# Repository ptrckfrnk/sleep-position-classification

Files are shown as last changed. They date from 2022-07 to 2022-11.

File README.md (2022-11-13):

# Electronic Technologies and Biosensors Laboratory

## Academic Year 2021/2022 - II Semester

## Final Project - Project 5 - Sleep position classifier
## Objective


The aim of this project was to develop a system able to correctly classify and forecast **12 specific sleep positions** (visible in the image above), using the data from **two accelerometers LIS3DH** placed one on the chest and one on the right ankle. 
The finished project includes: 
- development of the wearable device
- data acquisition
- data processing
- GUI for data sampling and visualization
- machine learning architecture able to perform sleep position classification

The PSoC communicates with the LIS3DH sensors using **I2C communication**, and the accelerometers have a sampling frequency set at 10Hz. 
The communication between the PSoC device and the pc was created using a **HC05 Bluetooth module** to make the device wearable.
Also, for wearability, the device is powered with a **9V battery** and a subsequent **9 to 5 voltage transformer**.
### Hardware
- 2 LIS3DH accelerometers
- 1 HC05 Bluetooth module
- 1 9V battery
- 1 9to5 voltage transformer
- 1 PSoC CY8CKIT-059 
- 1 breadboard
- 2 3D printed casings were used to encapsulate the accelerometers and place them on the body
- 10 2m long cables to connect the accelerometers to the PSoC
- 2 modular velcro bands to fix the accelerometers in place 

The links between the PSoC and the different components can be found in the dedicated folder in the form of the **hardware** **setup** documentation and the eagle schematic and board files.
The casing's 3D model can also be found in the dedicated folder.

### PSoC code
This section of code is responsible for I2C communication between the PSoC and the 2 accelerometers, which are sampling data with an ODR of 10Hz and are set on **FIFO mode**. The following code averages the 32 samples of the FIFO buffer from both accelerometers, each time they are simultaneously full.
Finally, the 6 averaged acceleration values (x, y and z from the chest and the ankle) are combined in a unique string and managed by the **UART** of the bluetooth module, having a baudrate of 9600 bps.

All code files of this section have been individually commented on for clarity.

### GUI code

This section of code deals with establishing a connection between pc and bluetooth module, visualizing the data sampled in real-time, and producing csv files following a specific sampling protocol, which are further used to train the machine learning module. 
It follows a description of the most important subsections of code, but the code has been commented throughout for clarity.
#### $Serial$ $interface$
This subsection is devoted to scanning all serial ports and creating a list used in the dropdown menu.
#### $Serial$ $Worker$
The **SerialWorker** class handles the connection with the bluetooth module by establishing a connection with the desired serial port (selectable in a drop down menu), reading data from this port from start (S) to end (E) tokens as soon as the Start button is pressed, **storing iteratively** the read lines in the data object and saving them at the end of the protocol in a single csv file.  
It's also responsible for sending char data on the serial port and closing the serial port before closing the app.
#### $Graphic$ $interface$ 
This sub-section of code deals with creating the **window** used by all the plot widgets and the various **buttons**. 
It's worth noting that the 6 data charts are plotted on the same window by first removing the oldest point, then adding the new one, and finally updating the data.
#### $Main$
The main is responsible for setting the **window size**, creating the **thread handler** and **initializing** all the **functions** previously mentioned.

### Machine Learning
#### $Install$

The Machine Learning portion of this project was created using a Jupyter Notebook.
The library used are available in the *requirements.txt* file inside the *machine learning folder* and any function needed is clearly listed and commented troughout the code.

#### $Data$
In order to run the code, it's necessary to upload the csv files produced by us during the sampling. All the paths are stored in a distinct variable.

The data consists in 11 csv files sampled from 11 different people, it's worth nothing that the file 'fabio_20220601_193018.csv' was discarted 
due to errors during the sampling procedure, thus we ended up with 10 different people, a sample size big enough to guarantee inter-subject variabilty.

The data available was studied in three different ways, in order to see if the accuracy of the model could be improved:
- **Raw** sampled data
- **Average** of data for each sensor
- **Average** of data for each sensor + **minimun and maximum** values for each sensor

#### $Data Preprocessing$
It's important to note that the **first 20 samples of each position recording were removed**, due to the patient still not being completely settled down and ready for the sampling. 
The data was also **normalized** as good practice dictates.

#### $Data Visualization$
The data was visualized multiple times, this allowed us to purge it from artifacts and anomalies and improve the learning algorithm, such as the *transient
data* between two positions mentioned in the previous paragraph.

#### $Features$
The data was gathered from 2 accelerometers, one on the chest and one on the right ankle. Therefore we have 6 inputs + 1 input for the subject's sex.
- x_chest
- y_chest
- z_chest
- x_ankle
- y_ankle
- z_ankle
- sex

#### $Target Variable$
The variable that we need to predict is the sleeping position. It can be one of twelve positions.

##### $Run$
To run the code, simply run sequentially every data cell. 
The code was tested on all three datasets, and the best performing one turned out to be the **Random Forest Classifier** learned using the **average+min_max** dataset, which reached **50% of accuracy** on the test set.

#### $Master Position$
In order to better assess the performance of the classifier we also tested it only on the four "master" positions: by grouping by three the positions (and therefore eliminating the small variations between each of the main positions) we obtained the **main positions**: supine, prone, left-sided and right-sided. 
When we tested our algorithm only with these targets, we easily obtained **100% accuracy**.

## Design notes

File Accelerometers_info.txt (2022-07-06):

Accelerometer 01 - Address 0x18 - Chest
Accelerometer 02 - Address 0x19 - Ankle

Ankle accelerometer has a black scotch mark, SD0 pin needs to be connected to Vin
Chest accelerometer SD0 pin needs to be connected to Gnd

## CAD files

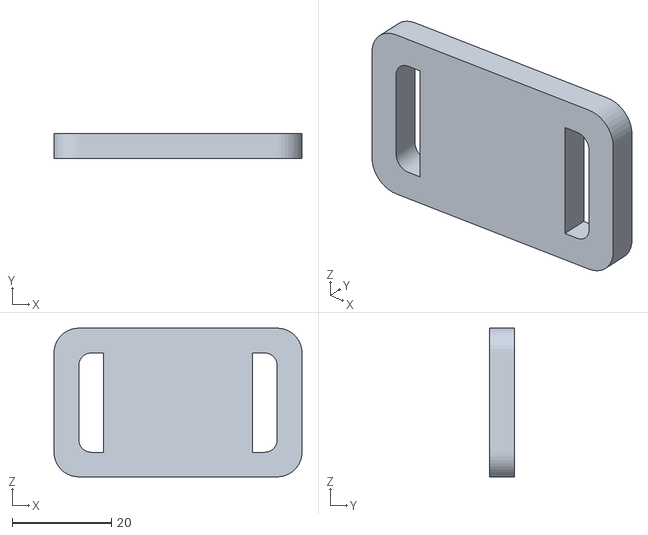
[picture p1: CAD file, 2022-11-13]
3D_Printing/Accelerometer_casing.STL
50.0 x 5.00 x 30.0

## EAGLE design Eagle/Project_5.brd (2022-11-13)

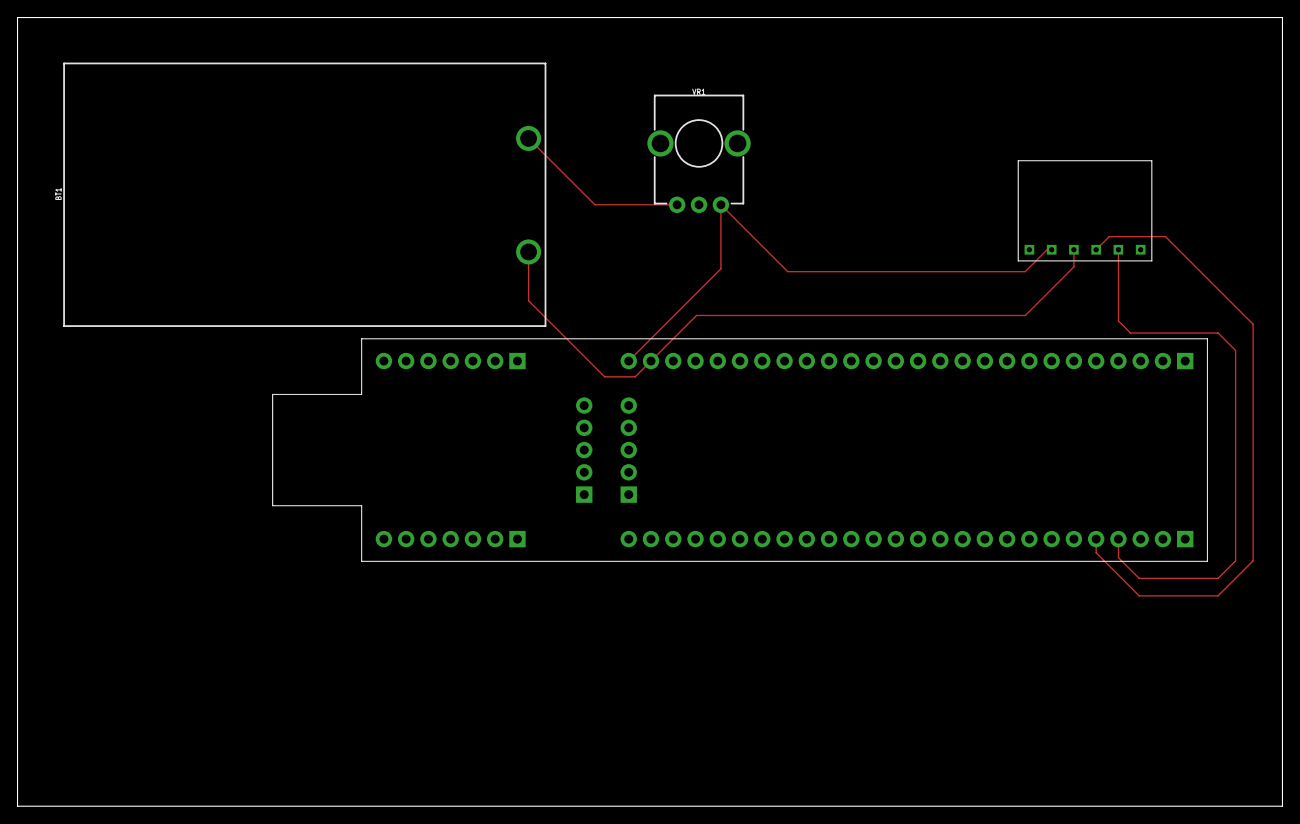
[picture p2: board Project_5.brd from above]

Board: 2 copper layers, 144.3 x 90.0 mm, 4 parts (0 on the bottom side), 5 nets.

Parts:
BT1: BATTCON_9V
U$1: CY8CKIT-059
U$2: HC; HC-05
VR1: 10k; POT-PTH-ALPS-KIT

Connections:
unnamed: BT1.-, U$1.25, U$2.P$4
unnamed: U$1.30, U$2.P$2
unnamed: U$1.31, U$2.P$3
unnamed: U$1.26, U$2.P$5, VR1.P$3
unnamed: BT1.+, VR1.P$1

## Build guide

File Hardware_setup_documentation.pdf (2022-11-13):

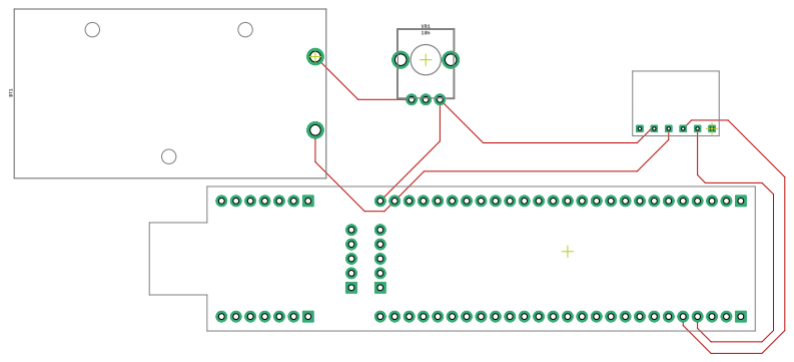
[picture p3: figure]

This board (on the right) is included in the documentation only for detailing purposes, since we did not produce a pcb (as it would have been superfluous). If one wanted to do it, only the components shown here (psoc, voltage transformer, bluetooth module and battery) would be needed, while the accelerometers would still need to be linked using external cables.

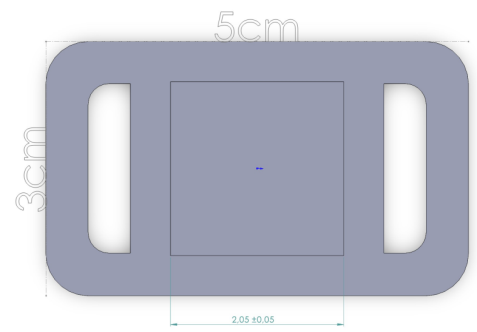
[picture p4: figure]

The casing model were created using solidworks and were then printed using the automaker software.

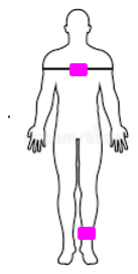
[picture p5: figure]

### Sleep Position Sensor

The hardware setup relies upon the links between the accelerometers and the bluetootooh module and the PSoC. We will describe the main connections (also visible on the pcb schematic on the left) for clarity.
Bluetooth
Rxd is linked to Port 0.7
Txd is linked to Port 0.6
Accelerometers
Scl are linked to port 12.0
Sda are linked to port 12.1
Notably, since both accelerometers are linked to same ports, in order to distinguish them we linked the Sdo of one accelerometer to the Power line, and the other one to the Ground line.

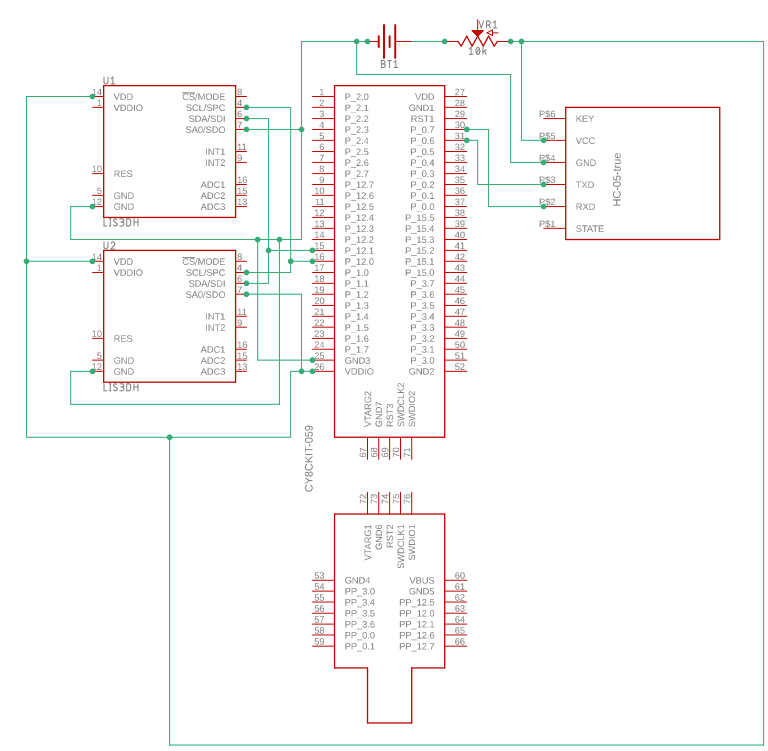
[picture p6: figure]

### Accelerometers casings

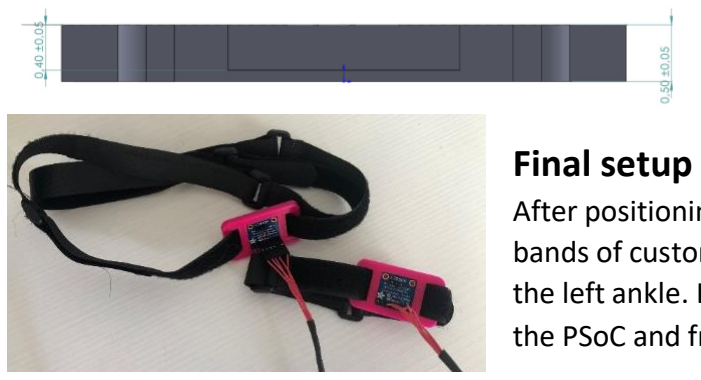
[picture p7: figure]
Final setup

After positioning the sensors inside the casings, we used velcro bands of customizable length to place them around the chest and the left ankle. Long cables (2m) were used to bring the signals to the PSoC and from there the bluetooth module sent them to the pc.

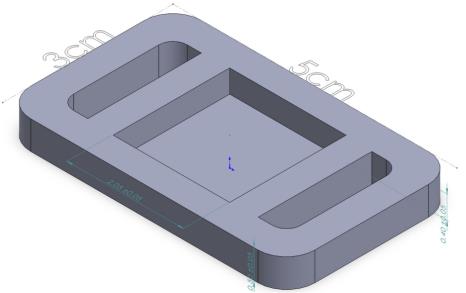
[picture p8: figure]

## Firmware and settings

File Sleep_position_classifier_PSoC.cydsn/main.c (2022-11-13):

/* ===============================================
 *
 * Alfonzo Massimo, Canavate Chloé, Franke Patrick
 * Project 05 - Sleep Position Classifier
 * Electronic Technologies and Biosensor Laboratory
 * Academic year 2021 - 2022
 * main.c file
 *
 * =============================================== */


#include <stdio.h>
#include "project.h"
#include "I2C_Interface.h"
#include "LIS3DH.h"

int main(void)
{
    CyGlobalIntEnable; /* Enable global interrupts. */

    I2C_Peripheral_Start();
    UART_BT_Start();

    CyDelay(5); // The boot procedure is complete about 5 ms after device power-up.

    // Bluetooth communication check
    UART_BT_PutString("UART BT: Communication started.\r\n");

    
    // CyDelay(100);
    
    // String to print out messages on the UART_BT
    char message[50] = {'\0'};
    
    // Read and write all the registers 
        // CTRL REG 1   (0x20)
    uint8_t ctrl_reg_1_acc_1;
    uint8_t ctrl_reg_1_acc_2;
    
    ErrorCode error_acc1 = I2C_Peripheral_ReadRegister(LIS3DH_1_DEVICE_ADDRESS, 
                                                    LIS3DH_CTRL_REG1,
                                                    &ctrl_reg_1_acc_1);
    ErrorCode error_acc2 = I2C_Peripheral_ReadRegister(LIS3DH_2_DEVICE_ADDRESS, 
                                                    LIS3DH_CTRL_REG1,
                                                    &ctrl_reg_1_acc_2);
        
            // Acc 1 reading
    if (error_acc1 == NO_ERROR) 
    {
        sprintf(message, "CTRL REG 1 value - Accelerometer 1: 0x%02X\r\n", ctrl_reg_1_acc_1);
        UART_BT_PutString(message);
    }
    else
    {
        UART_BT_PutString("I2C error while reading CTRL REG 1 - Accelerometer 1\r\n");
    }
            // Acc 2 reading
    if (error_acc2 == NO_ERROR) 
    {
        sprintf(message, "CTRL REG 1 value - Accelerometer 2: 0x%02X\r\n", ctrl_reg_1_acc_2);
        UART_BT_PutString(message);
    }
    else
    {
        UART_BT_PutString("I2C error while reading CTRL REG 1 - Accelerometer 2\r\n");
    }
    
            // Acc 1 writing if necessary
    if (ctrl_reg_1_acc_1 != LIS3DH_NORMAL_MODE_CTRL_REG1)
    {
        ctrl_reg_1_acc_1 = LIS3DH_NORMAL_MODE_CTRL_REG1;
        
        error_acc1 = I2C_Peripheral_WriteRegister(LIS3DH_1_DEVICE_ADDRESS,
                                                  LIS3DH_CTRL_REG1,
                                                  ctrl_reg_1_acc_1);
        
        if (error_acc1 == NO_ERROR)
        {
            sprintf(message, "\r\nCTRL REG 1 - Accelerometer 1 successfully written as: 0x%02X\r\n", ctrl_reg_1_acc_1);
            UART_BT_PutString(message);
        }
        else
        {
            UART_BT_PutString("\r\nI2C error while writing CTRL REG 1 - Accelerometer 1\r\n");
        }
    }

            // Acc 2 writing if necessary
    if (ctrl_reg_1_acc_2 != LIS3DH_NORMAL_MODE_CTRL_REG1)
    {
        ctrl_reg_1_acc_2 = LIS3DH_NORMAL_MODE_CTRL_REG1;
        
        error_acc2 = I2C_Peripheral_WriteRegister(LIS3DH_2_DEVICE_ADDRESS,
                                                  LIS3DH_CTRL_REG1,
                                                  ctrl_reg_1_acc_2);
        
        if (error_acc2 == NO_ERROR)
        {
            sprintf(message, "\r\nCTRL REG 1 - Accelerometer 2 successfully written as: 0x%02X\r\n", ctrl_reg_1_acc_2);
            UART_BT_PutString(message);
        }
        else
        {
            UART_BT_PutString("\r\nI2C error while writing CTRL REG 1 - Accelerometer 2\r\n");
        }
    }
    
        // CTRL REG 5   (0x24)
    uint8_t ctrl_reg_5_acc_1;
    uint8_t ctrl_reg_5_acc_2;
    
    error_acc1 = I2C_Peripheral_ReadRegister(LIS3DH_1_DEVICE_ADDRESS, 
                                             LIS3DH_CTRL_REG5,
                                             &ctrl_reg_5_acc_1);
    error_acc2 = I2C_Peripheral_ReadRegister(LIS3DH_2_DEVICE_ADDRESS, 
                                             LIS3DH_CTRL_REG5,
                                             &ctrl_reg_5_acc_2);
    
            // Acc 1 reading
    if (error_acc1 == NO_ERROR) 
    {
        sprintf(message, "CTRL REG 5 value - Accelerometer 1: 0x%02X\r\n", ctrl_reg_5_acc_1);
        UART_BT_PutString(message);
    }
    else
    {
        UART_BT_PutString("I2C error while reading CTRL REG 5 - Accelerometer 1\r\n");
    }
            // Acc 2 reading
    if (error_acc2 == NO_ERROR) 
    {
        sprintf(message, "CTRL REG 5 value - Accelerometer 2: 0x%02X\r\n", ctrl_reg_5_acc_2);
        UART_BT_PutString(message);
    }
    else
    {
        UART_BT_PutString("I2C error while reading CTRL REG 5 - Accelerometer 2\r\n");
    }
    
            // Acc 1 writing if necessary
    if (ctrl_reg_5_acc_1 != LIS3DH_NORMAL_MODE_CTRL_REG5)
    {
        ctrl_reg_5_acc_1 = LIS3DH_NORMAL_MODE_CTRL_REG5;
        
        error_acc1 = I2C_Peripheral_WriteRegister(LIS3DH_1_DEVICE_ADDRESS,
                                                  LIS3DH_CTRL_REG5,
                                                  ctrl_reg_5_acc_1);
        
        if (error_acc1 == NO_ERROR)
        {
            sprintf(message, "\r\nCTRL REG 5 - Accelerometer 1 successfully written as: 0x%02X\r\n", ctrl_reg_5_acc_1);
            UART_BT_PutString(message);
        }
        else
        {
            UART_BT_PutString("\r\nI2C error while writing CTRL REG 5 - Accelerometer 1\r\n");
        }
    }
            // Acc 2 writing if necessary
    if (ctrl_reg_5_acc_2 != LIS3DH_NORMAL_MODE_CTRL_REG5)
    {
        ctrl_reg_5_acc_2 = LIS3DH_NORMAL_MODE_CTRL_REG5;
        
        error_acc2 = I2C_Peripheral_WriteRegister(LIS3DH_2_DEVICE_ADDRESS,
                                                  LIS3DH_CTRL_REG5,
                                                  ctrl_reg_5_acc_2);
        
        if (error_acc2 == NO_ERROR)
        {
            sprintf(message, "\r\nCTRL REG 5 - Accelerometer 2 successfully written as: 0x%02X\r\n", ctrl_reg_5_acc_2);
            UART_BT_PutString(message);
        }
        else
        {
            UART_BT_PutString("\r\nI2C error while writing CTRL REG 5 - Accelerometer 2\r\n");
        }
    }
    
        //FIFO CTRL REG     (0x2E)
    uint8_t fifo_ctrl_reg_acc_1;
    uint8_t fifo_ctrl_reg_acc_2;
    error_acc1 = I2C_Peripheral_ReadRegister(LIS3DH_1_DEVICE_ADDRESS, 
                                             LIS3DH_FIFO_CTRL_REG,
                                             &fifo_ctrl_reg_acc_1);
    error_acc2 = I2C_Peripheral_ReadRegister(LIS3DH_2_DEVICE_ADDRESS, 
                                             LIS3DH_FIFO_CTRL_REG,
                                             &fifo_ctrl_reg_acc_2);
    
            // Acc 1 reading
    if (error_acc1 == NO_ERROR)
    {
        sprintf(message, "FIFO CTRL REG value - Accelerometer 1: 0x%02X\r\n", fifo_ctrl_reg_acc_1);
        UART_BT_PutString(message);
    }
    else
    {
        UART_BT_PutString("I2C error while reading FIFO CTRL REG - Accelerometer 1\r\n");
    }
            // Acc 2 reading
    if (error_acc2 == NO_ERROR )
    {
        sprintf(message, "FIFO CTRL REG value - Accelerometer 2: 0x%02X\r\n", fifo_ctrl_reg_acc_2);
        UART_BT_PutString(message);
    }
    else
    {
        UART_BT_PutString("I2C error while reading FIFO CTRL REG - Accelerometer 2\r\n");
    }
    
            // Acc 1 writing if necessary
    if (fifo_ctrl_reg_acc_1 != LIS3DH_BYPASS_MODE)
    {
        fifo_ctrl_reg_acc_1 = LIS3DH_BYPASS_MODE;
        
        error_acc1 = I2C_Peripheral_WriteRegister(LIS3DH_1_DEVICE_ADDRESS,
                                                  LIS3DH_FIFO_CTRL_REG,
                                                  fifo_ctrl_reg_acc_1);
            
        if (error_acc1 == NO_ERROR)
        {
            sprintf(message, "\r\nFIFO CTRL REG - Accelerometer 1 successfully written as: 0x%02X\r\n", fifo_ctrl_reg_acc_1);
            UART_BT_PutString(message);
        }
        else
        {
            UART_BT_PutString("\r\nI2C error while writing FIFO CTRL REG - Accelerometer 1\r\n");
        }
    }
            // Acc 2 writing if necessary
    if (fifo_ctrl_reg_acc_2 != LIS3DH_BYPASS_MODE)
    {
        fifo_ctrl_reg_acc_2 = LIS3DH_BYPASS_MODE;
        
        error_acc2 = I2C_Peripheral_WriteRegister(LIS3DH_2_DEVICE_ADDRESS,
                                                  LIS3DH_FIFO_CTRL_REG,
                                                  fifo_ctrl_reg_acc_2);
        
        if (error_acc2 == NO_ERROR)
        {
            sprintf(message, "\r\nFIFO CTRL REG - Accelerometer 2 successfully written as: 0x%02X\r\n", fifo_ctrl_reg_acc_2);
            UART_BT_PutString(message);
        }
        else
        {
            UART_BT_PutString("\r\nI2C error while writing FIFO CTRL REG - Accelerometer 2\r\n");
        }
    }


    // Sample the data
    int16_t register_count = 192;
    uint8_t Acc1_data[192];
    uint8_t Acc2_data[192];
    uint8_t fifo_full_2;
    uint8_t fifo_full_1;

        // Switch the 2 accelerometers to FIFO mode
    error_acc2 = I2C_Peripheral_WriteRegister(LIS3DH_2_DEVICE_ADDRESS,
                                              LIS3DH_FIFO_CTRL_REG,
                                              LIS3DH_FIFO_MODE_CTRL_REG_MODE);
    error_acc1 = I2C_Peripheral_WriteRegister(LIS3DH_1_DEVICE_ADDRESS,
                                              LIS3DH_FIFO_CTRL_REG,
                                              LIS3DH_FIFO_MODE_CTRL_REG_MODE);
    for(;;)
    {
        CyDelay(500); // highly needed to get stable data

        error_acc1 = I2C_Peripheral_ReadRegister(LIS3DH_1_DEVICE_ADDRESS,
                                                 LIS3DH_FIFO_SRC_REG,
                                                 &fifo_full_1);
        
        error_acc2 = I2C_Peripheral_ReadRegister(LIS3DH_2_DEVICE_ADDRESS,
                                                 LIS3DH_FIFO_SRC_REG,
                                                 &fifo_full_2);
        
        if (error_acc1 == NO_ERROR && error_acc2 == NO_ERROR)
        {
            CyDelay(50);
            uint8_t OVRN_FIFO_2 = (fifo_full_2 & 0x40) >> 6;
            uint8_t OVRN_FIFO_1 = (fifo_full_1 & 0x40) >> 6;
            
            // Check if the FIFO of both accelerometers are full
            if (OVRN_FIFO_1 == 0x01 && OVRN_FIFO_2 == 0x01)
            {
                I2C_Peripheral_ReadRegisterMulti(LIS3DH_2_DEVICE_ADDRESS,
                                                 LIS3DH_OUT_X_L,
                                                 register_count,
                                                 Acc2_data);
                
                I2C_Peripheral_ReadRegisterMulti(LIS3DH_1_DEVICE_ADDRESS,
                                                 LIS3DH_OUT_X_L,
                                                 register_count,
                                                 Acc1_data);
                
                // Accelerometer 1 (0x18)
                int16_t x1 = 0;
                int16_t y1 = 0;
                int16_t z1 = 0;
                
                // Empty and store the 32 samples of the FIFO
                for (int i = 0; i < 32; i++)
                {
                    x1 += (int16)(Acc1_data[i*6] | (Acc1_data[i*6+1] << 8)) >> 6;
                    y1 += (int16)(Acc1_data[i*6+2] | (Acc1_data[i*6+3] << 8)) >> 6;
                    z1 += (int16)(Acc1_data[i*6+4] | (Acc1_data[i*6+5] << 8)) >> 6;
                }
                
                // Compute the mean
                int16_t x1_mean = x1 / 32;
                int16_t y1_mean = y1 / 32;
                int16_t z1_mean = z1 / 32;
                
                // Accelerometer 2 (0x19)
                int16_t x2 = 0;
                int16_t y2 = 0;
                int16_t z2 = 0;
                
                // Empty and store the 32 samples of the FIFO
                for (int i = 0; i < 32; i++)
                {
                    x2 += (int16)(Acc2_data[i*6] | (Acc2_data[i*6+1] << 8)) >> 6;
                    y2 += (int16)(Acc2_data[i*6+2] | (Acc2_data[i*6+3] << 8)) >> 6;
                    z2 += (int16)(Acc2_data[i*6+4] | (Acc2_data[i*6+5] << 8)) >> 6;
                }
                
                // Compute the mean
                int16_t x2_mean = x2 / 32;
                int16_t y2_mean = y2 / 32;
                int16_t z2_mean = z2 / 32;
                
                // Send message to BT module containing start (S) and end (E) characterers, along with the 6 acc means
                sprintf(message, "S %d,%d,%d,%d,%d,%d E", x1_mean, y1_mean, z1_mean, x2_mean, y2_mean, z2_mean);
                UART_BT_PutString(message);
                
                
                CyDelay(200);
                
                // Bypass mode followed by FIFO mode to reset the FIFO
                error_acc2 = I2C_Peripheral_WriteRegister(LIS3DH_2_DEVICE_ADDRESS,
                                                          LIS3DH_FIFO_CTRL_REG,
                                                          LIS3DH_BYPASS_MODE);
                
                error_acc2 = I2C_Peripheral_WriteRegister(LIS3DH_2_DEVICE_ADDRESS,
                                                          LIS3DH_FIFO_CTRL_REG,
                                                          LIS3DH_FIFO_MODE_CTRL_REG_MODE);
                
                error_acc1 = I2C_Peripheral_WriteRegister(LIS3DH_1_DEVICE_ADDRESS,
                                                          LIS3DH_FIFO_CTRL_REG,
                                                          LIS3DH_BYPASS_MODE);
                
                error_acc1 = I2C_Peripheral_WriteRegister(LIS3DH_1_DEVICE_ADDRESS,
                                                          LIS3DH_FIFO_CTRL_REG,
                                                          LIS3DH_FIFO_MODE_CTRL_REG_MODE);
            }
        }
    }
}

/* [] END OF FILE */

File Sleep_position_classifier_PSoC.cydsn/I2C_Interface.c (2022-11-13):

/* ===============================================
 *
 * Alfonzo Massimo, Canavate Chloé, Franke Patrick
 * Project 05 - Sleep Position Classifier
 * Electronic Technologies and Biosensor Laboratory
 * Academic year 2021 - 2022
 * I2C_Interface.c file
 * \brief This file includes all the required source
 * code to interface the I2C peripheral
 *
 * =============================================== */


/**
*   \brief Value returned if device present on I2C bus.
*/
#ifndef DEVICE_CONNECTED
    #define DEVICE_CONNECTED 1
#endif

/**
*   \brief Value returned if device not present on I2C bus.
*/
#ifndef DEVICE_UNCONNECTED
    #define DEVICE_UNCONNECTED 0
#endif

#include "I2C_Interface.h" 
#include "I2C.h"

ErrorCode I2C_Peripheral_Start(void) 
{
    // Start I2C peripheral
    I2C_Start();  
    
    // Return no error since start function does not return any error
    return NO_ERROR;
}

// --------------------------------------------------------------------------------- //

ErrorCode I2C_Peripheral_Stop(void)
{
    // Stop I2C peripheral
    I2C_Stop();
    // Return no error since stop function does not return any error
    return NO_ERROR;
}

// --------------------------------------------------------------------------------- //

ErrorCode I2C_Peripheral_ReadRegister(uint8_t device_address, 
                                      uint8_t register_address,
                                      uint8_t* data) {
    
    // Start Condition
    uint8_t error = I2C_MasterSendStart(device_address, I2C_WRITE_XFER_MODE);                                        
    if (error == I2C_MSTR_NO_ERROR)
    {
        //Write the register address to be read
        error = I2C_MasterWriteByte(register_address);
        if (error == I2C_MSTR_NO_ERROR)
        {
            // Send a restart condition
            error = I2C_MasterSendRestart(device_address, I2C_READ_XFER_MODE);
            if (error == I2C_MSTR_NO_ERROR)
            {
                *data = I2C_MasterReadByte(I2C_NAK_DATA);
            }
        }
    }
    // Stop Comunication
    I2C_MasterSendStop();
    //Return
    return error ? ERROR : NO_ERROR;
    
}
                                    
// --------------------------------------------------------------------------------- //

ErrorCode I2C_Peripheral_ReadRegisterMulti(uint8_t device_address,
                                           uint8_t register_address,
                                           uint8_t register_count,
                                           uint8_t* data) {
    
    // Send start condition
    uint8_t error = I2C_MasterSendStart(device_address, I2C_WRITE_XFER_MODE);
    if (error == I2C_MSTR_NO_ERROR)
    {
        // Write register address to be read with the MSB = 1
        register_address |= 0x80; //Datasheet indication for multi read -- autoincrement
        error = I2C_MasterWriteByte(register_address);
        if (error == I2C_MSTR_NO_ERROR)
        {
            // Send Restart condition
            error = I2C_MasterSendRestart(device_address, I2C_READ_XFER_MODE);
            if (error == I2C_MSTR_NO_ERROR)
            {
                // Continue to read until we have register to be read
                uint8_t counter = register_count;
                while (counter > 1)
                {
                    data[register_count - counter] = 
                        I2C_MasterReadByte(I2C_ACK_DATA);
                        counter --;
                }
                // Read last data without acknolowledgment
                data[register_count - 1] = 
                    I2C_MasterReadByte(I2C_NAK_DATA);
            }
        }
    }
    // Send Stop Condition
    I2C_MasterSendStop();
    // Return Error Code
    return error ? ERROR : NO_ERROR;
                                              
}
                                        
// --------------------------------------------------------------------------------- //

ErrorCode I2C_Peripheral_WriteRegister(uint8_t device_address,
                                       uint8_t register_address,
                                       uint8_t data) {
    
    
    // Send Start Condition
    uint8_t error = I2C_MasterSendStart(device_address, I2C_WRITE_XFER_MODE);
    if (error == I2C_MSTR_NO_ERROR)
    {
        //Write Register Address (to be overwritten)
        error = I2C_MasterWriteByte(register_address);
        if (error == I2C_MSTR_NO_ERROR)
        {
            // Write Byte
            error = I2C_MasterWriteByte(data);
        }
    }
    // Close Communication
    I2C_MasterSendStop();
    // Return
    return error ? ERROR : NO_ERROR;
}
                                    

                                            
// --------------------------------------------------------------------------------- //

uint8_t I2C_Peripheral_IsDeviceConnected(uint8_t device_address) {
    
    // Send a start condition followed by a stop condition
    uint8_t error = I2C_MasterSendStart(device_address, I2C_WRITE_XFER_MODE);
    I2C_MasterSendStop();
    // If no error generated during stop, device is connected
    return (error == I2C_MSTR_NO_ERROR ? DEVICE_CONNECTED : DEVICE_UNCONNECTED);
    
}

/* [] END OF FILE */

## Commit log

2022-04-29 Setup of TopDesign, I2C lines and BridgeControl files
2022-05-04 Added UART for debugging
2022-05-04 Adapted I2C master
2022-05-04 Get 3-axis data from both accelerometers
2022-05-04 Added UART_BT
2022-05-04 Try X acc UART_BT
2022-05-13 Able to read data over bluetooth and modified GUI
    [bluetooth_output.csv]
2022-05-13 Slight changes to the sample function
2022-05-18 Updated data aquisition and improved sample function.
2022-05-25 Deleted unnecessary files and renamed main file
    [bluetooth_output.csv]
2022-05-25 Working version of sample function with CSV export
    [bluetooth_data_20220525_153840.csv, bluetooth_data_20220525_153926.csv, bluetooth_data_20220525_154009.csv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]
2022-05-25 New bluetooth sampling data
    [bluetooth_data_20220525_174830.csv, bluetooth_data_20220525_175350.csv, bluetooth_data_20220525_184443.csv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]
2022-05-25 Modified CSV file
    [bluetooth_data_20220525_190239.csv]
2022-05-27 Added interrupted sampling v1
    [bluetooth_data_20220527_105646.csv, bluetooth_data_20220527_115136.csv, bluetooth_data_20220527_115429.csv]
2022-05-28 accelerometers info
    [bluetooth_data_20220527_105646.csv, bluetooth_data_20220527_115136.csv, bluetooth_data_20220527_115429.csv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]
2022-05-30 Initialized Worker Thread for sampling function
2022-06-06 Data acquisition
    [alessandra_20220601_182359.csv, aurora_20220601_180419.csv, benedetta_20220601_184141.csv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]
2022-06-12 Last samplings
    [axel_20220610_193124.csv, lilian_20220610_214447.csv]
2022-06-12 Added an Excel data analysis
    [data_analysis.xlsx]
2022-07-04 New GUI functionality - Acceleration plot
    [bluetooth_data_20220525_153840.csv, bluetooth_data_20220525_153926.csv, bluetooth_data_20220525_154009.csv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]
2022-07-06 Cleaned branch
    [alessandra_20220601_182359.csv, aurora_20220601_180419.csv, axel_20220610_193124.csv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]
2022-07-06 Added correct PSoC project
    [I2C_Interface.c, main.c]
2022-07-06 Added dataset folder
    [alessandra_20220601_182359.csv, aurora_20220601_180419.csv, axel_20220610_193124.csv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]
2022-07-06 Added data visualization
    [alessandra_20220601_182359.csv, aurora_20220601_180419.csv, axel_20220610_193124.csv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]
2022-07-06 Reorganized folders
    [alessandra_20220601_182359.csv, aurora_20220601_180419.csv, axel_20220610_193124.csv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]
2022-07-06 Changed file path to local
    [melissa_20220601_190124.csv]
2022-11-13 Add 3D printing data of casing
    [Accelerometer_casing.STL]
2022-11-13 Add PCB schematics data in EAGLE
    [Project_5.brd, Project_5.sch]
2022-11-13 Improved readability and corrected typos
    [I2C_Interface.c, main.c]

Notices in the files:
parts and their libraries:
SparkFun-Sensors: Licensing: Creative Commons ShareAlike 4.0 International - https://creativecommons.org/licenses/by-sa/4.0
